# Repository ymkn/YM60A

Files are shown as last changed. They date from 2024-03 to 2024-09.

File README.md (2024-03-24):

# YM60A

An ANSI-style layout for use on Japanese 106/109 layouts 60% hot swappable custom mechanical keyboard PCB powered by RP2040. Suitable for most Poker-compatible 60% keyboard cases.

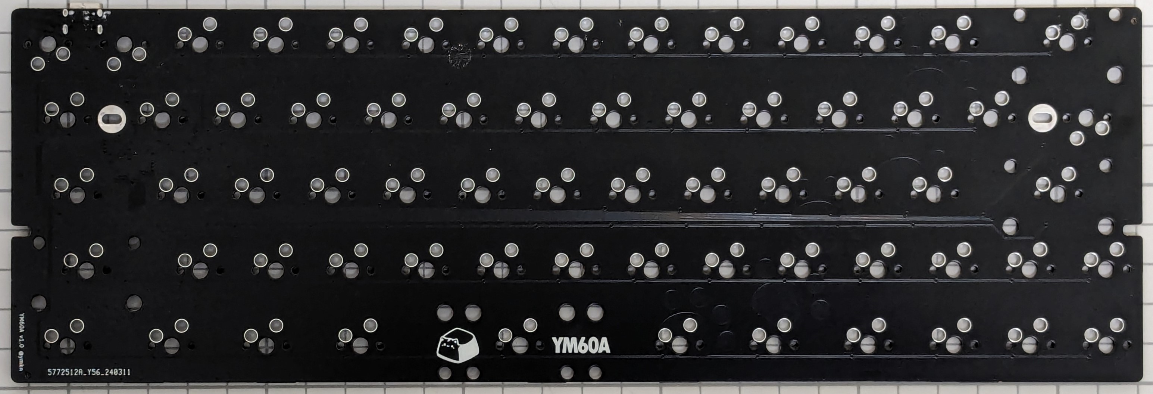
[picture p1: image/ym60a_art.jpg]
YM60A Art


## Default Layout

You can customize the layout with [Vial](https://get.vial.today/) configurator.

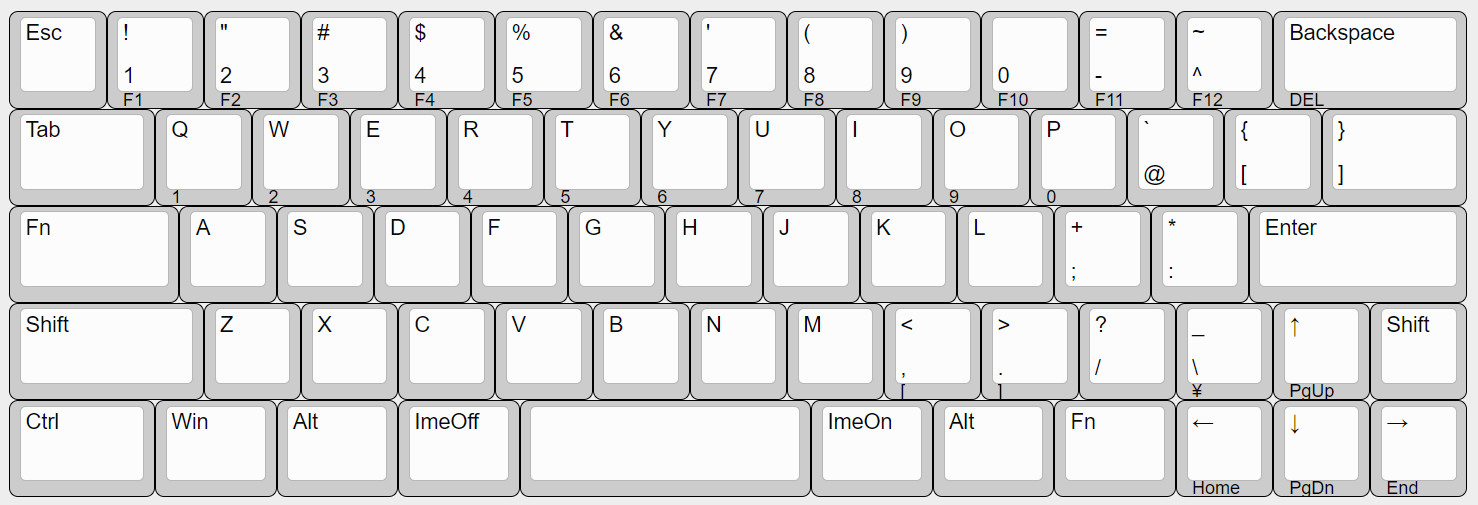
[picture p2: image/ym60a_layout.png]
YM60A Layout


Spacebar can be swap 3u to 2.25/2.75u with 2u stabilizers if you don't have 3u spacebar and its stabilizers.

## Specification

- MX compatible switches
- USB-C Connector (USB 2.0)
- Hot swappable
- Dimension: 285mm(w) x 94.6mm(h) x 1.6mm(d)
- Suitable for most 60% keyboard cases
  - Warning: center and right bottom mounting holes are not implemented.

## Build Guide

See [doc/buildguide.md](doc/buildguide.md)

## LICENSE

This project is licensed under the MIT License, see the [LICENSE file](LICENSE) for details.

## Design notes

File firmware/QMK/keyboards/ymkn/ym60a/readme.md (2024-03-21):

# ymkn/YM60A

YM60A - A ANSI layout for Japanese users 60% hot swappable custom mechanical keyboard PCB powered by RP2040.

* Keyboard Maintainer: [ymkn](https://github.com/ymkn)

Make example for this keyboard (after setting up your build environment):

    make ymkn/ym60a:vial

Flashing example for this keyboard:

1. Enter the bootloader.
2. Simply copy ymkn_ym60a_vial.uf2 to RPI_RP2 drive.

This keyboard supports [Vial](https://get.vial.today/) configurator.

## Bootloader

Enter the bootloader in 2 ways:

* **Bootmagic reset**: Hold down the key at (0,0) in the matrix (usually the top left key or Escape) and plug in the keyboard
* **Physical reset button**: Briefly press the button on the back of the PCB - some may have pads you must short instead

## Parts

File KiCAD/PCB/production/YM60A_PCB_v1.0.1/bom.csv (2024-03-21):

Designator | Footprint | Quantity | Value | LCSC Part #
BTN1 | SW_Push_1P1T_XKB_TS-1187A | 1 | TS-1187A-B-A-B
C1, C2 | 0402 | 2 | 10uF
C10, C13, C16, C17, C3, C4, C5, C6, C7, C8, C9 | 0402 | 11 | 100nF
C11, C12 | 0402 | 2 | 1uF
C14, C15 | 0402 | 2 | 20pF
D1, D10, D11, D12, D13, D14, D15, D16, D17, D18, D19, D2, D20, D21, D22, D23, D24, D25, D26, D27, D28, D29, D3, D30, D31, D32, D33, D34, D35, D36, D37, D38, D39, D4, D40, D41, D42, D43, D44, D45, D46, D47, D48, D49, D5, D50, D51, D52, D53, D54, D55, D56, D57, D58, D59, D6, D61, D62, D63, D64, D65, D66, D67, D7, D8, D9 | D_SOD-123 | 66 | 1N4148W
J1 | USB_C_Receptacle_HRO_TYPE-C-31-M-12 | 1 | TYPE-C-31-M-12
R1, R3 | 0402 | 2 | 5.1K
R4, R5 | 0603 | 2 | 27
R6 | 0402 | 1 | 1KΩ
R7 | 0402 | 1 | 10kΩ
R8 | 0402 | 1 | 1K
U1 | SOT-23-3 | 1 | XC6206P332MR
U2 | SOT-363-6_2P2X1P35_ONS | 1 | SMF05CT1G
U3 | QFN-56-1EP_7x7mm_P0.4mm_EP3.2x3.2mm | 1 | RP2040
U4 | W25Q16JVUXIQ_WIN | 1 | W25Q16JVUXIQ
Y1 | Crystal_SMD_3225-4Pin_3.2x2.5mm | 1 | X322512MSB4SI

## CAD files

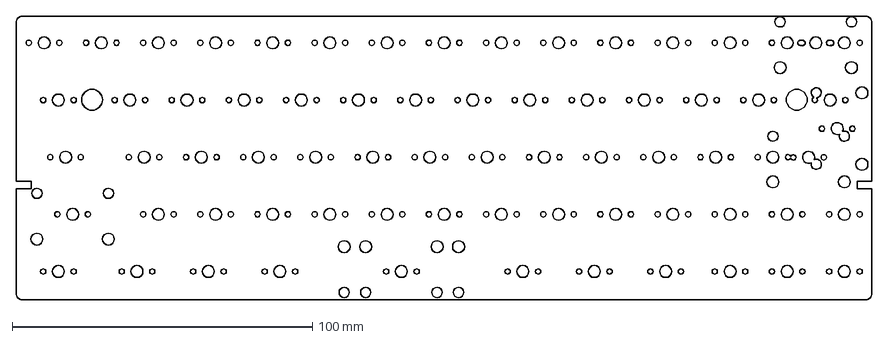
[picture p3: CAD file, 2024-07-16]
KiCAD/SwitchPad/YM60_SwitchPad.dxf
285.0 x 94.6 mm

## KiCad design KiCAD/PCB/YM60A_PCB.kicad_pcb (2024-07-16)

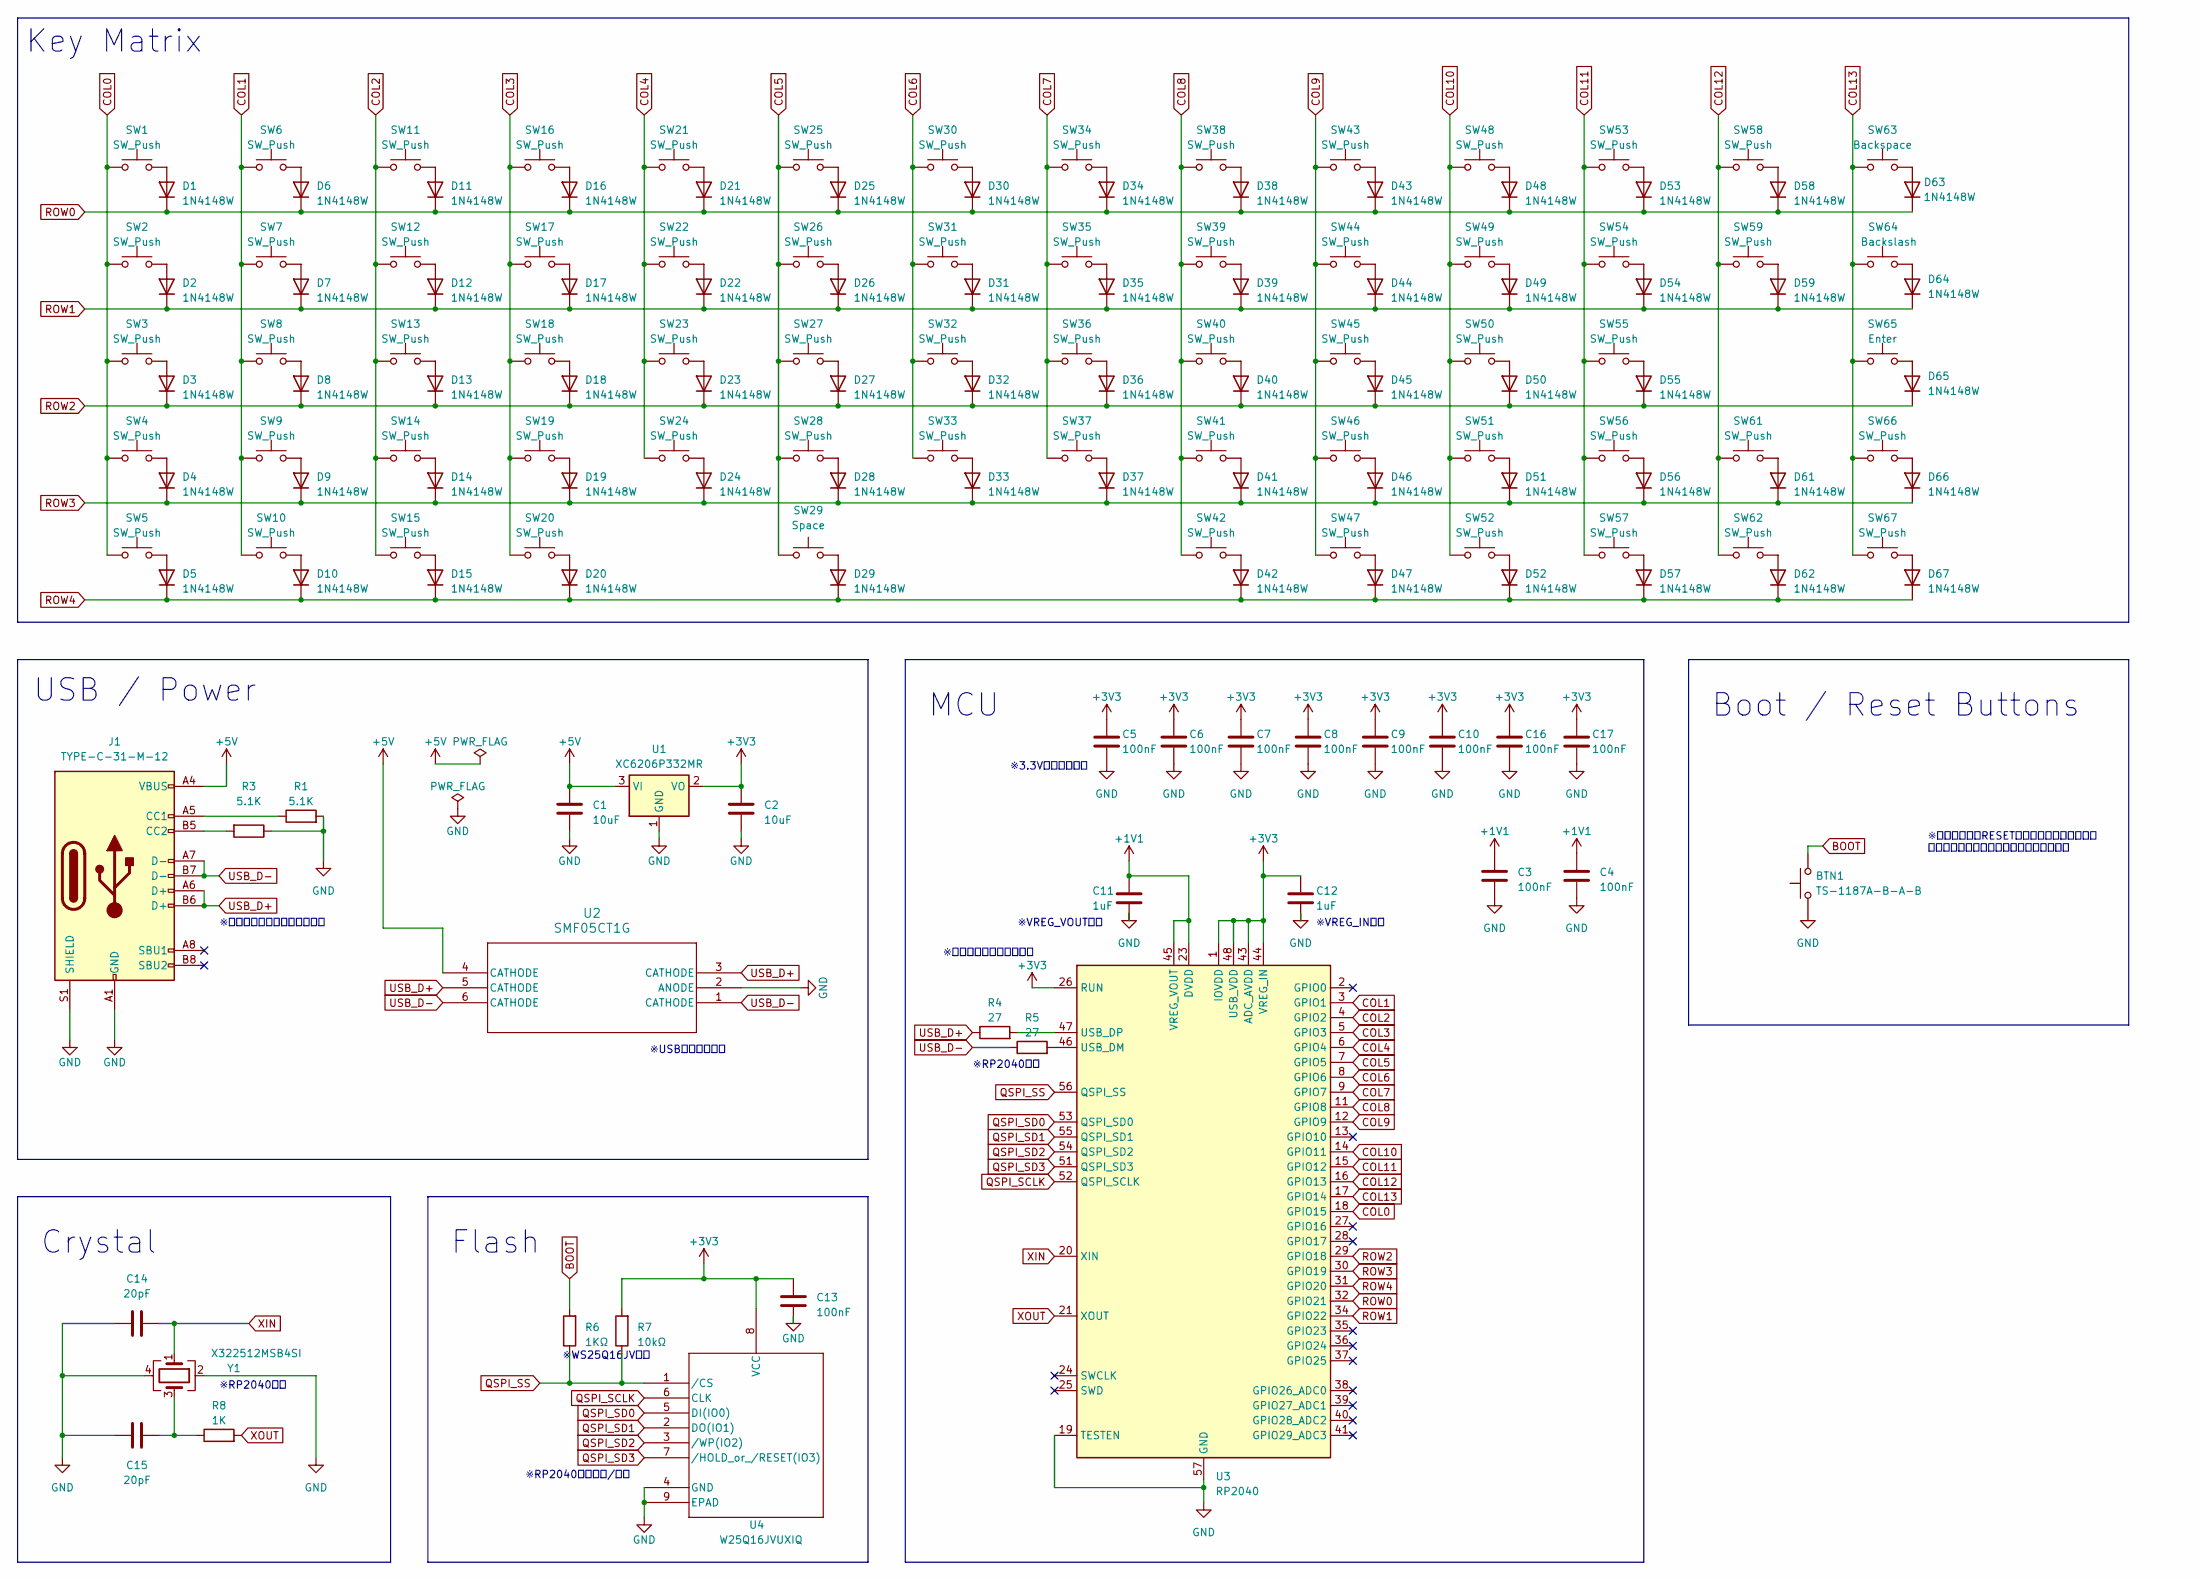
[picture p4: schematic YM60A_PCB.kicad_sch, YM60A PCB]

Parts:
BTN1: TS-1187A-B-A-B; SW_Push_1P1T_XKB_TS-1187A; LCSC Parts # C318884
C1, C2: 10uF; C_0402_1005Metric; LCSC Parts # C15525
C3, C4, C5, C6, C7, C8, C9, C10, C13, C16, C17: 100nF; C_0402_1005Metric; LCSC Parts # C1525
C11, C12: 1uF; C_0402_1005Metric; LCSC Parts # C52923
C14, C15: 20pF; C_0402_1005Metric; LCSC Parts # C1554
D1, D2, D3, D4, D5, D6, D7, D8, D9, D10, D11, D12, D13, D14, D15, D16, D17, D18, D19, D20, D21, D22, D23, D24, D25, D26, D27, D28, D29, D30, D31, D32, D33, D34, D35, D36, D37, D38, D39, D40, D41, D42, D43, D44, D45, D46, D47, D48, D49, D50, D51, D52, D53, D54, D55, D56, D57, D58, D59, D61, D62, D63, D64, D65, D66, D67: 1N4148W; D_SOD-123; LCSC Parts # C81598
J1: TYPE-C-31-M-12; USB_C_Receptacle_HRO_TYPE-C-31-M-12; LCSC Parts # C165948
R1, R3: 5.1K; R_0402_1005Metric; LCSC Parts # C25905
R4, R5: 27; R_0603_1608Metric; LCSC Parts # C13167
R6: 1KΩ; R_0402_1005Metric; LCSC Parts # C11702
R7: 10kΩ; R_0402_1005Metric; LCSC Parts # C25744
R8: 1K; R_0402_1005Metric; LCSC Parts # C11702
SW1, SW4, SW6, SW7, SW8, SW9, SW11, SW12, SW13, SW14, SW16, SW17, SW18, SW19, SW21, SW22, SW23, SW24, SW25, SW26, SW27, SW28, SW30, SW31, SW32, SW33, SW34, SW35, SW36, SW37, SW38, SW39, SW40, SW41, SW43, SW44, SW45, SW46, SW48, SW49, SW50, SW51, SW53, SW54, SW55, SW56, SW57, SW58, SW59, SW61, SW62, SW66, SW67: SW_Push; SW_MX_HS_CPG151101S11_1u
SW2, SW5: SW_Push; SW_MX_HS_CPG151101S11_1.5u
SW3: SW_Push; SW_MX_HS_CPG151101S11_1.75u
SW10, SW15, SW20, SW42, SW47, SW52: SW_Push; SW_MX_HS_CPG151101S11_1.25u
SW29: Space; SW_MX_HS_CPG151101S11_1u
SW63: Backspace; SW_MX_HS_CPG151101S11_1u
SW64: Backslash; SW_MX_HS_CPG151101S11_1.5u
SW65: Enter; SW_MX_HS_CPG151101S11_1u
U1: XC6206P332MR; SOT-23-3; LCSC Parts # C5446
U2: SMF05CT1G; SOT-363-6_2P2X1P35_ONS; LCSC Parts # C15879
U3: RP2040; QFN-56-1EP_7x7mm_P0.4mm_EP3.2x3.2mm; LCSC Parts # C2040
U4: W25Q16JVUXIQ; W25Q16JVUXIQ_WIN; LCSC Parts # C2843335
Y1: X322512MSB4SI; Crystal_SMD_3225-4Pin_3.2x2.5mm; LCSC Parts # C9002

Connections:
+1V1: C3.1, C4.1, C11.1, U3.23 (DVDD), U3.45 (VREG_VOUT), U3.50 (DVDD)
+3V3: C2.1, C5.1, C6.1, C7.1, C8.1, C9.1, C10.1, C12.1, C13.1, C16.1, C17.1, R7.2, U1.2 (VO), U3.1 (IOVDD), U3.10 (IOVDD), U3.22 (IOVDD), U3.26 (RUN), U3.33 (IOVDD), U3.42 (IOVDD), U3.43 (ADC_AVDD), U3.44 (VREG_IN), U3.48 (USB_VDD), U3.49 (IOVDD), U4.8 (VCC)
+5V: C1.1, J1.A4 (VBUS), J1.A9 (VBUS), J1.B4 (VBUS), J1.B9 (VBUS), U1.3 (VI), U2.4 (CATHODE)
BOOT: BTN1.2, R6.2
COL0: SW1.1, SW2.1, SW3.1, SW4.1, SW5.1, U3.18 (GPIO15)
COL1: SW6.1, SW7.1, SW8.1, SW9.1, SW10.1, U3.3 (GPIO1)
COL2: SW11.1, SW12.1, SW13.1, SW14.1, SW15.1, U3.4 (GPIO2)
COL3: SW16.1, SW17.1, SW18.1, SW19.1, SW20.1, U3.5 (GPIO3)
COL4: SW21.1, SW22.1, SW23.1, SW24.1, U3.6 (GPIO4)
COL5: SW25.1, SW26.1, SW27.1, SW28.1, SW29.1, U3.7 (GPIO5)
COL6: SW30.1, SW31.1, SW32.1, SW33.1, U3.8 (GPIO6)
COL7: SW34.1, SW35.1, SW36.1, SW37.1, U3.9 (GPIO7)
COL8: SW38.1, SW39.1, SW40.1, SW41.1, SW42.1, U3.11 (GPIO8)
COL9: SW43.1, SW44.1, SW45.1, SW46.1, SW47.1, U3.12 (GPIO9)
COL10: SW48.1, SW49.1, SW50.1, SW51.1, SW52.1, U3.14 (GPIO11)
COL11: SW53.1, SW54.1, SW55.1, SW56.1, SW57.1, U3.15 (GPIO12)
COL12: SW58.1, SW59.1, SW61.1, SW62.1, U3.16 (GPIO13)
COL13: SW63.1, SW64.1, SW65.1, SW66.1, SW67.1, U3.17 (GPIO14)
GND: BTN1.1, C1.2, C2.2, C3.2, C4.2, C5.2, C6.2, C7.2, C8.2, C9.2, C10.2, C11.2, C12.2, C13.2, C14.1, C15.1, C16.2, C17.2, J1.A1 (GND), J1.A12 (GND), J1.B1 (GND), J1.B12 (GND), J1.S1 (SHIELD), R1.2, R3.1, U1.1 (GND), U2.2 (ANODE), U3.19 (TESTEN), U3.57 (GND), U4.4 (GND), U4.9 (EPAD), Y1.2, Y1.4
unnamed: C15.2, R8.1, Y1.3
unnamed: D1.2 (A), SW1.2
unnamed: D2.2 (A), SW2.2
unnamed: D3.2 (A), SW3.2
unnamed: D4.2 (A), SW4.2
unnamed: D5.2 (A), SW5.2
unnamed: D6.2 (A), SW6.2
unnamed: D7.2 (A), SW7.2
unnamed: D8.2 (A), SW8.2
unnamed: D9.2 (A), SW9.2
unnamed: D10.2 (A), SW10.2
unnamed: D11.2 (A), SW11.2
unnamed: D12.2 (A), SW12.2
unnamed: D13.2 (A), SW13.2
unnamed: D14.2 (A), SW14.2
unnamed: D15.2 (A), SW15.2
unnamed: D16.2 (A), SW16.2
unnamed: D17.2 (A), SW17.2
unnamed: D18.2 (A), SW18.2
unnamed: D19.2 (A), SW19.2
unnamed: D20.2 (A), SW20.2
unnamed: D21.2 (A), SW21.2
unnamed: D22.2 (A), SW22.2
unnamed: D23.2 (A), SW23.2
unnamed: D24.2 (A), SW24.2
unnamed: D25.2 (A), SW25.2
unnamed: D26.2 (A), SW26.2
unnamed: D27.2 (A), SW27.2
unnamed: D28.2 (A), SW28.2
unnamed: D29.2 (A), SW29.2
unnamed: D30.2 (A), SW30.2
unnamed: D31.2 (A), SW31.2
unnamed: D32.2 (A), SW32.2
unnamed: D33.2 (A), SW33.2
unnamed: D34.2 (A), SW34.2
unnamed: D35.2 (A), SW35.2
unnamed: D36.2 (A), SW36.2
unnamed: D37.2 (A), SW37.2
unnamed: D38.2 (A), SW38.2
unnamed: D39.2 (A), SW39.2
unnamed: D40.2 (A), SW40.2
unnamed: D41.2 (A), SW41.2
unnamed: D42.2 (A), SW42.2
unnamed: D43.2 (A), SW43.2
unnamed: D44.2 (A), SW44.2
unnamed: D45.2 (A), SW45.2
unnamed: D46.2 (A), SW46.2
unnamed: D47.2 (A), SW47.2
unnamed: D48.2 (A), SW48.2
unnamed: D49.2 (A), SW49.2
unnamed: D50.2 (A), SW50.2
unnamed: D51.2 (A), SW51.2
unnamed: D52.2 (A), SW52.2
unnamed: D53.2 (A), SW53.2
unnamed: D54.2 (A), SW54.2
unnamed: D55.2 (A), SW55.2
unnamed: D56.2 (A), SW56.2
unnamed: D57.2 (A), SW57.2
unnamed: D58.2 (A), SW58.2
unnamed: D59.2 (A), SW59.2
unnamed: D61.2 (A), SW61.2
unnamed: D62.2 (A), SW62.2
unnamed: D63.2 (A), SW63.2
unnamed: D64.2 (A), SW64.2
unnamed: D65.2 (A), SW65.2
unnamed: D66.2 (A), SW66.2
unnamed: D67.2 (A), SW67.2
unnamed: J1.A5 (CC1), R1.1
unnamed: J1.B5 (CC2), R3.2
unnamed: R5.2, U3.46 (USB_DM)
unnamed: R4.2, U3.47 (USB_DP)
QSPI_SCLK: U3.52 (QSPI_SCLK), U4.6 (CLK)
QSPI_SD0: U3.53 (QSPI_SD0), U4.5 (DI(IO0))
QSPI_SD1: U3.55 (QSPI_SD1), U4.2 (DO(IO1))
QSPI_SD2: U3.54 (QSPI_SD2), U4.3 (/WP(IO2))
QSPI_SD3: U3.51 (QSPI_SD3), U4.7 (/HOLD_or_/RESET(IO3))
QSPI_SS: R6.1, R7.1, U3.56 (QSPI_SS), U4.1 (/CS)
ROW0: D1.1 (K), D6.1 (K), D11.1 (K), D16.1 (K), D21.1 (K), D25.1 (K), D30.1 (K), D34.1 (K), D38.1 (K), D43.1 (K), D48.1 (K), D53.1 (K), D58.1 (K), D63.1 (K), U3.32 (GPIO21)
ROW1: D2.1 (K), D7.1 (K), D12.1 (K), D17.1 (K), D22.1 (K), D26.1 (K), D31.1 (K), D35.1 (K), D39.1 (K), D44.1 (K), D49.1 (K), D54.1 (K), D59.1 (K), D64.1 (K), U3.34 (GPIO22)
ROW2: D3.1 (K), D8.1 (K), D13.1 (K), D18.1 (K), D23.1 (K), D27.1 (K), D32.1 (K), D36.1 (K), D40.1 (K), D45.1 (K), D50.1 (K), D55.1 (K), D65.1 (K), U3.29 (GPIO18)
ROW3: D4.1 (K), D9.1 (K), D14.1 (K), D19.1 (K), D24.1 (K), D28.1 (K), D33.1 (K), D37.1 (K), D41.1 (K), D46.1 (K), D51.1 (K), D56.1 (K), D61.1 (K), D66.1 (K), U3.30 (GPIO19)
ROW4: D5.1 (K), D10.1 (K), D15.1 (K), D20.1 (K), D29.1 (K), D42.1 (K), D47.1 (K), D52.1 (K), D57.1 (K), D62.1 (K), D67.1 (K), U3.31 (GPIO20)
USB_D+: J1.A6 (D+), J1.B6 (D+), R4.1, U2.3 (CATHODE), U2.5 (CATHODE)
USB_D-: J1.A7 (D-), J1.B7 (D-), R5.1, U2.1 (CATHODE), U2.6 (CATHODE)
XIN: C14.2, U3.20 (XIN), Y1.1
XOUT: R8.2, U3.21 (XOUT)

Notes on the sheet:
※RP2040近傍
Flash
Key Matrix
※リセットボタン実装無し
USB / Power
※WS25Q16JV近傍
※USBコネクタ近傍
※差動信号、配線長さ合わせる
※VREG_IN近傍
Boot / Reset Buttons
MCU
※3.3V電源ピン近傍
※RP2040近傍配置/直結
※VREG_VOUT近傍
Crystal
※以前はここにRESETボタンの回路があった。 基板スペースと費用の都合で削除した。

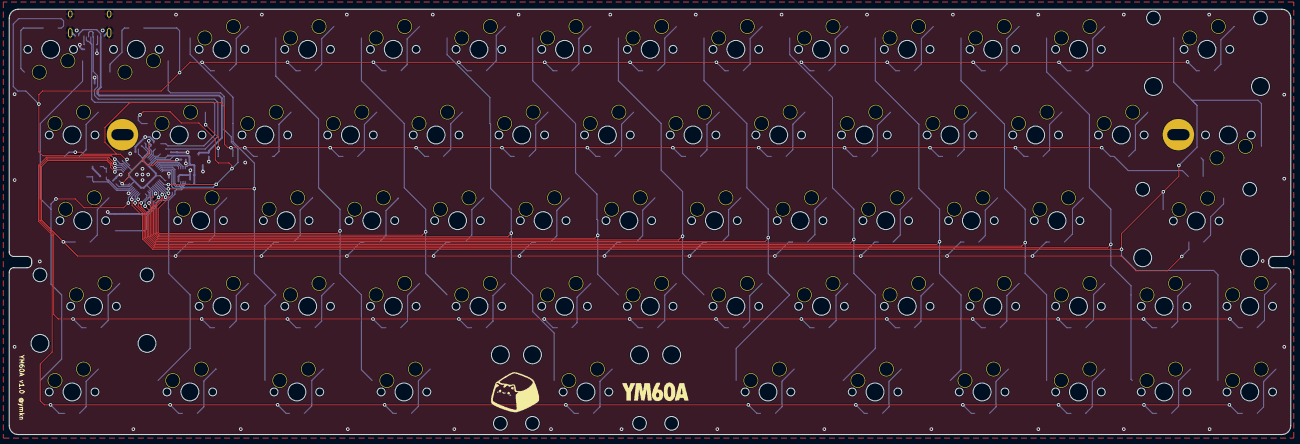
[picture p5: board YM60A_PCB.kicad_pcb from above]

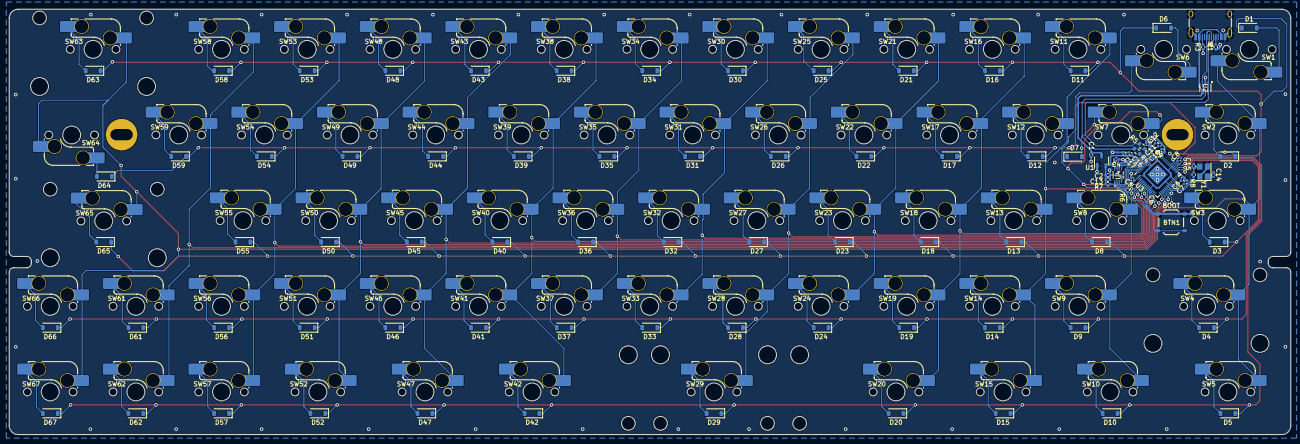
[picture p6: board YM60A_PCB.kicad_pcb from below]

Board: 2 copper layers, 285.1 x 94.6 mm, 163 parts (163 on the bottom side), 105 nets.

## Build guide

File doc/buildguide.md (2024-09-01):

# YM60A ビルドガイド

## 1. はじめに

本書は自作キーボード基板であるYM60Aのビルドガイドです。キーボードとして利用可能になるまでの手順を初心者向けに丁寧に記載したつもりですが、不明な個所などある場合は適時検索するなどして補ってください。

申し訳ないのですがYM60A固有でない一般のご質問にはお答えできません。各自お調べください。

**キーボード自作経験者向け：** 必要なことはCherry MX用スイッチソケットの調達とそのはんだ付けだけです。ファームウェアはQMKが書き込み済みで、キーマップ変更はVialに対応しています。これでわかればここから先を読む必要はありません。

## 2. 準備

### 2.1 内容物確認

YM60Aは本体となる基板とキースイッチ固定用のトッププレートのセットです。しかし、これだけではキーボードとして使うことができません。その他必要な部品を別途調達いただく必要があります。

|品目|数量|
|---|---|
|YM60A 基板|1|
|YM60A トッププレート|1|

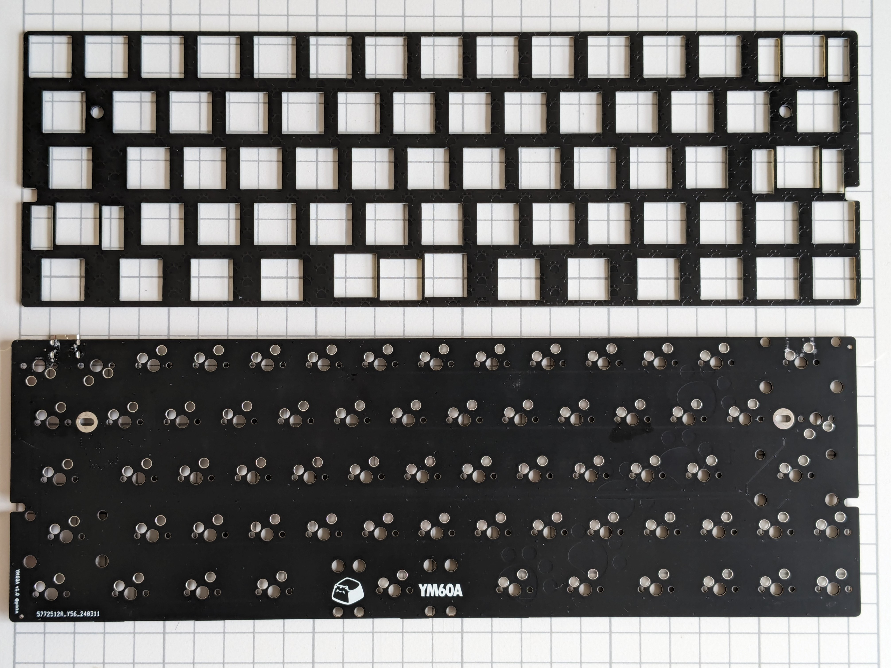
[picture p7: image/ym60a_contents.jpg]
YM60A内容物


> [!NOTE]
> スイッチパッドセットを購入した場合は、YM60A基板の代わりにYM60A基板（1.2mm厚、緑色）が、加えてニトリルゴム製スイッチパッド（0.4mm厚）が含まれます。
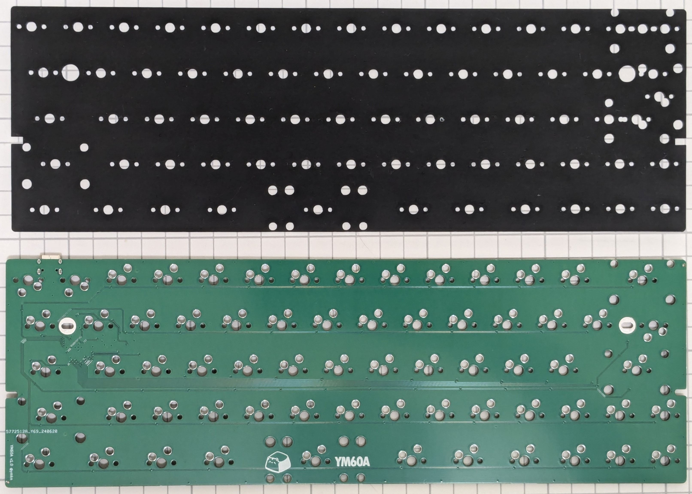
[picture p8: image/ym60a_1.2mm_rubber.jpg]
YM60Aスイッチパッドセット
> 

### 2.2 別途用意が必要な部品

下記部品は国内外の自作キーボード専門店や電子部品販売店などから別途調達してください。

|品目|数量|備考|
|---|---|---|
|MX互換キースイッチ|66|[Cherry MX](https://www.cherrymx.de/en/dev.html)もしくはその互換品|
|MX互換スイッチソケット|66|[Kailh PCB Socket CPG151101S11](https://www.kailhswitch.com/mechanical-keyboard-switches/box-switches/mechanical-keyboard-switches-kailh-pcb-socket.html)もしくはその互換品|
|MX互換キーキャップ|-|[Cherry MX](https://www.cherrymx.de/en/dev.html)もしくはその互換品|
|2uサイズPCBマウント型スタビライザー|3|幅の広いキーの押し下げを安定させる部品です。Backspaceキー、左Shiftキー、Enterキーに用います|
|2u or 3uサイズPCBマウント型スタビライザー|1|幅の広いキーの押し下げを安定させる部品です。スペースキーに用います。3uスタビライザーと3uスペースキーの組み合わせが推奨です。2uスタビライザーと2.75uスペースキーの組み合わせでも代用可能ですが、隙間が空きます|
|Poker互換60%サイズキーボードケース）|1|Poker互換、60%、GH60対応品、などと称して販売されているトップマウント型のケースが利用できます（※すべてのケースで完全な互換性を保証するものではありません）|

#### 必要なキーキャップとサイズ

必要なキーキャップとそのサイズは下図の通りです。キーのサイズは正方形のキーの幅を「1u」と呼称します。2uであれば1uの2倍の幅のキーであることを示します。幅は0.25u刻みで様々なサイズがあります。

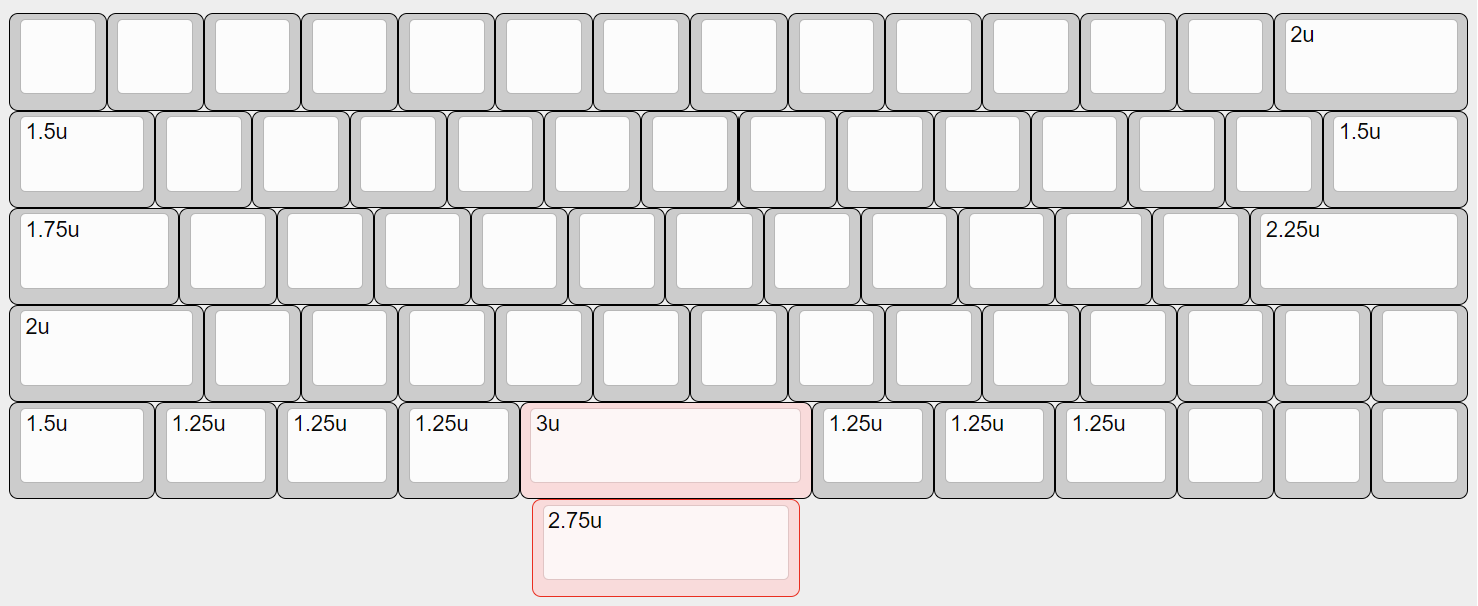
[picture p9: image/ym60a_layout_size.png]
レイアウト


このうち、標準的なANSI/ISOレイアウト向けのキーキャップセットに含まれていないか、オプション扱いであることが多い注意すべきキーは次の通りです。オプションを購入するか、同じサイズの別の印字のキーキャップで代替してください。

|行|サイズ|初期レイアウトの対応キー名|
|---|---|---|
|R4|2u|左Shiftキー|
|R4|1u|「ろ」の位置のキー|
|R4|1u|右Shiftキー|
|R5|1.25u|無変換、変換、Fn|
|R5|3u|スペースキー|

スペースキーは3uが推奨ですが、3uのスペースキーを用意できない場合は2.75uや2.25uでも代用できます（ただし左右に隙間が空きます）。

### 2.3 道具

|品目|数量|備考|
|---|---|---|
|はんだごて、はんだ|1|スイッチソケットのはんだ付けに用います。はんだごては調温機能付きのものを、はんだは鉛入りのものを推奨します|
|ピンセット|1|スイッチソケットのはんだ付けの際にあると便利です|
|ねじ回し（プラス）|1|基板をケースに固定する際に用います|

## 3. 組み立て

### 3.1 スイッチソケットのはんだ付け

スイッチソケットは基板の裏面（ICチップ等が実装されている面）に取り付けます。L字状のガイドが白線でキー数分印刷されていますので、そのすべてにスイッチソケットをはんだ付けします。

ICチップ近辺のソケットをはんだ付けする際は、はんだごてで電子部品をを焼いてしまわないように気を付けてください。

すべてのスイッチソケットが基板に密着しており、ソケット両端とも漏れなくはんだ付けされているか確認してください。基板から浮いていたり、はんだ付けができていないとキースイッチの動作不良の原因になります。

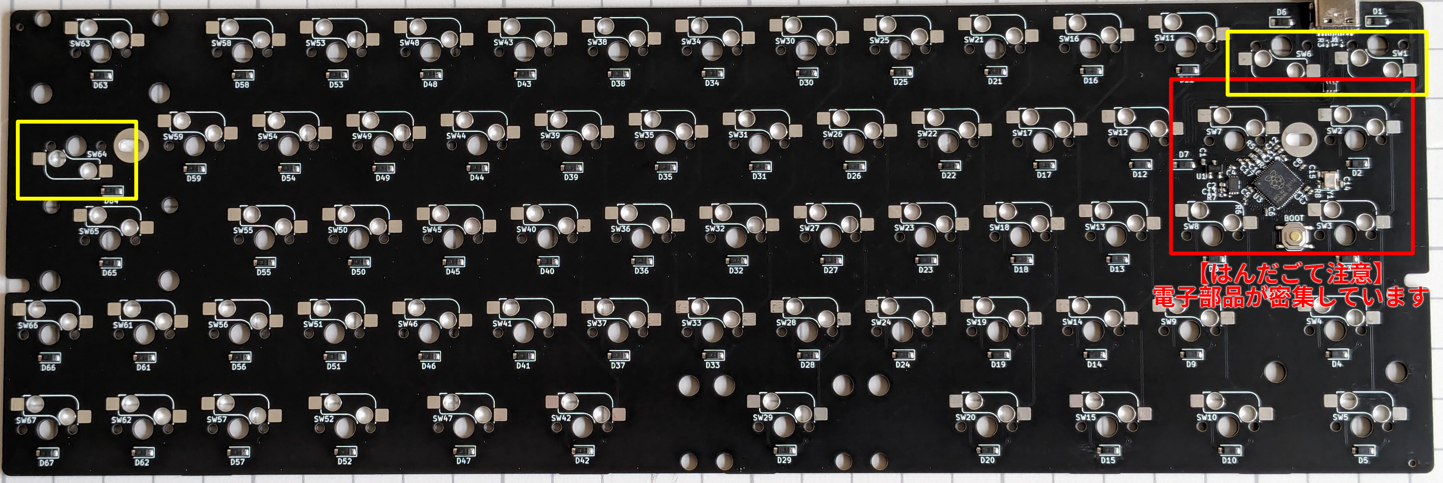
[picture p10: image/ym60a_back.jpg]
YM60A裏面


> [!CAUTION]
> 最上段の右端2つ、2段目左端の3つだけ、スイッチソケットの向きが上下逆になっているので注意してください。

### 3.2 スタビライザーの取り付け

> [!WARNING]
> スイッチパッドセットを購入した場合は、スイッチパッドを基板表面の上に敷き、その上からスタビライザーの取り付けを行ってください。

スタビライザーは基板の表面（ロゴが印刷されている面）に取り付けます。

左ShiftキーとEnterキーに2uサイズを、スペースキーに3uサイズ（2.75u以下のキーを代用する場合は2uサイズ）のスタビライザーを取り付けます。取り付け方はスタビライザーごとに異なりますが、一般には大きい穴の方にツメを引っかけ、小さい穴の方にプッシュピンを差し込む、もしくはネジ留めを行います。

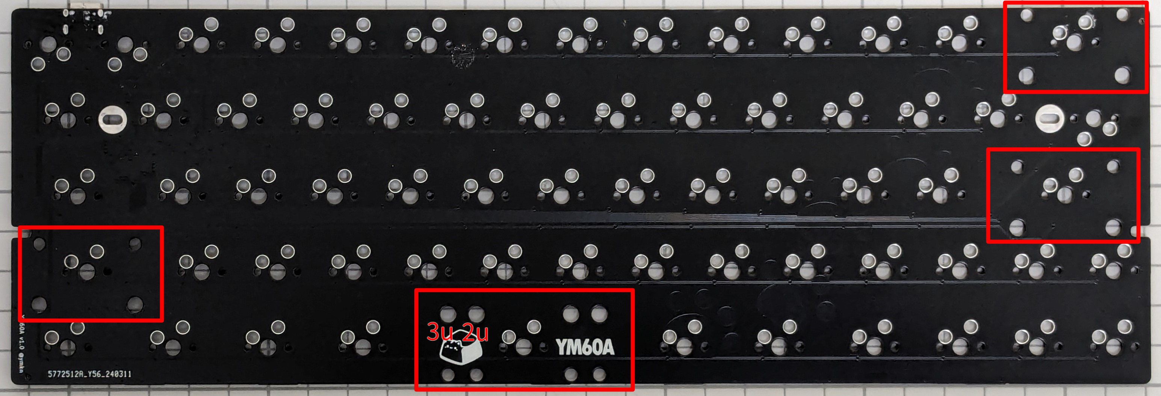
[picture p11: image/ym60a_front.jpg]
YM60A表面


### 3.3 スイッチの取り付け

キースイッチはトッププレートを通して基板のソケットに差し込みます。すべてのキースイッチを一度に取り付けてしまうと基板に差し込むのが大変なので、まずトッププレートの四隅にキースイッチを取り付けて基板に差し込み、その後残りのスイッチを取り付けていくのがおすすめです。

> [!NOTE]
> スイッチパッドにはキースイッチのピン部分の穴は開いておりません。キースイッチのピン自身で簡単に穴を開けられますので、そのまま押し込んでください。

### 3.4 ケースへの取り付け

Poker互換ケースにはネジ穴が6つほどあることが多いですが、本基板で利用できるのはそのうち4つのみとなります（中央と右下のネジ穴は使えません）。また、各ケース微妙にネジ穴やUSBコネクタ用穴の位置が異なるため位置が合わないことがありますが、その場合は留められる穴だけネジ留めしておけば問題ありません。

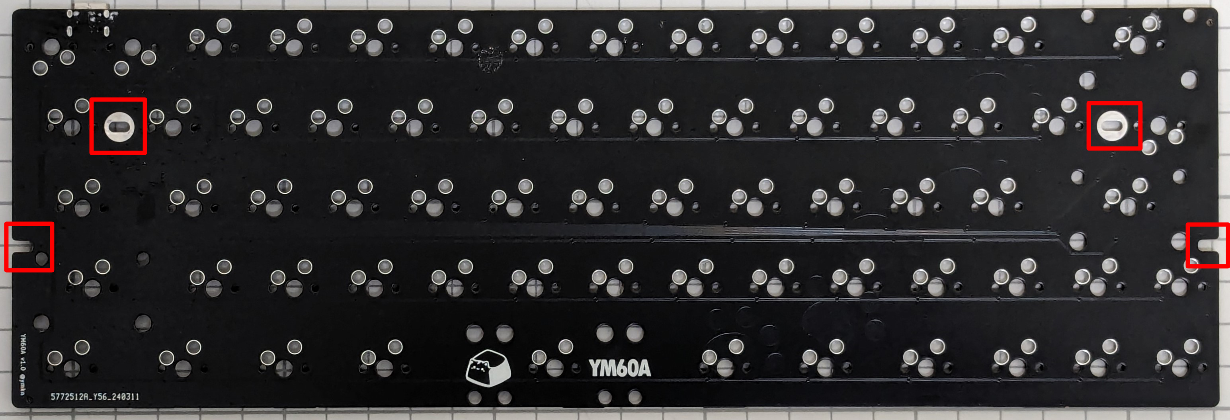
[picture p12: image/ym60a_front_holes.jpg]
YM60Aネジ穴


また、一部のプラ製ケースなどでは構造が基板底面近くまでせり出しているものがあります。本基板はスイッチソケット分の厚みが基板底面から1.8mm程度ありますので、そのような構造と干渉することがあります。ケース側を加工するか、長めのネジに交換するなどの対応をしてください。

基板をケースに取り付けられれば完成です！

## 4. 使用

## 4.1 コンピュータとの接続

お使いのコンピュータのUSB 2.0に対応したUSBコネクタと接続してください。即時利用できるはずです。

> [!NOTE]
> スイッチパッドを使用した場合、スイッチのピンで穴を開けた際の切れ端がソケットの接点を塞ぎ、スイッチの接触が悪くなることがよくあります。キーの反応が悪い場合はスイッチを何度か差し直してみてください。

## 4.2 キーマップのカスタマイズ

本キーボードは[Vial](https://get.vial.today/)というキーマップ変更ツールに対応しています。Vialの詳しい使いかたはVialのドキュメントや世間の情報を参考にしてください。

### 漢字キー（日本語入力On/Off用のキー）について

本キーボードの初期レイアウトに漢字キーの割り当てはありません。その代わり、スペースキーの左側のキーをImeOffキーに、右側のキーをImeOnキーに割り当てています。ImeOnキーとImeOffキーはWindows 10 1903以降でMicrosoft IMEを使用している場合に利用可能です。漢字キーが必要な場合はレイアウトをカスタマイズして任意のキーに割り当ててください。

参考： [キーボード日本 \- ImeOn / ImeOff の実装 \| Microsoft Learn](https://learn.microsoft.com/ja-jp/windows-hardware/design/component-guidelines/keyboard-japan-ime)

## 5. その他

### 5.1 ブートモードの入り方

RP2040のブートモードに入るには、左上のキー（Escキー）を押しながらUSBケーブルを接続します。

もしくは、基板裏面のBOOTスイッチを押しながらUSBケーブルを接続します。

### 5.2 ファームウェアのありか

本リポジトリ内で公開しています。

https://github.com/ymkn/YM60A/blob/main/firmware/QMK/ymkn_ym60a_vial.uf2

### 5.3 ソースコード/設計データのありか

本リポジトリ内で公開しています。MITライセンスです。

https://github.com/ymkn/YM60A

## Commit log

2024-03-24 ビルドガイドの追加
2024-07-16 スイッチパッド設計データ追加
    [YM60_SwitchPad.dxf, YM60_SwitchPad.kicad_pcb]
2024-07-16 ビルドガイドにスイッチパッドセットに関する記述を追加
2024-09-01 画像抜けを更新
2024-09-01 基板厚みの誤記を修正
